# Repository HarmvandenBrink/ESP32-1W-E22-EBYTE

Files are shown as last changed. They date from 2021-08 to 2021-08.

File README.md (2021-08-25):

# ESP32 1W E22-400M30S / E22-900M30S
ESP32-based EBYTE E22-400M30S / E22-900M30S compatible 1 Watt board

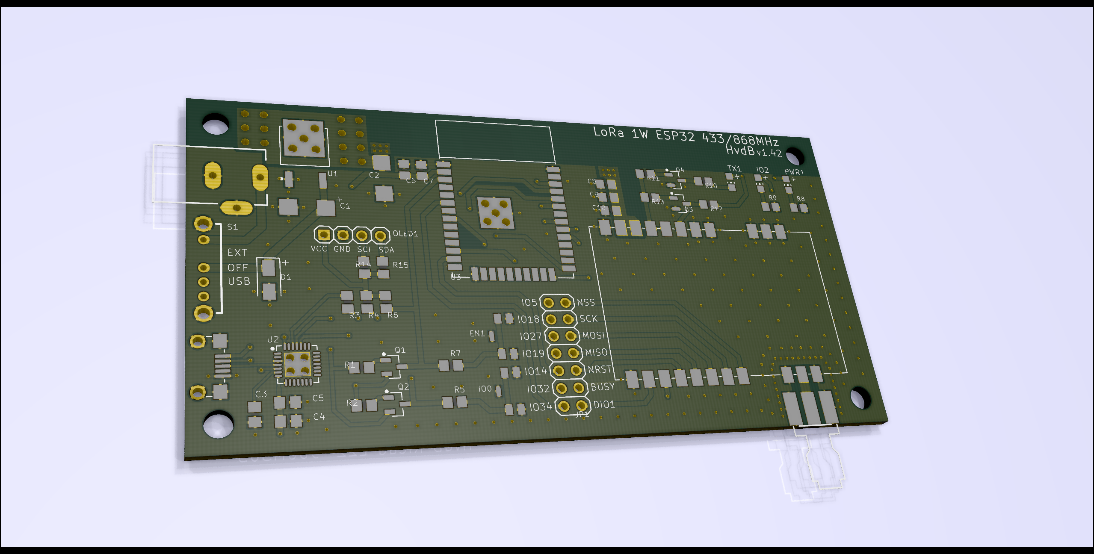
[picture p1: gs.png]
Board design in KiCAD


Forked the design, changed it to KiCAD.

## Features:
* Fully compatible with https://github.com/G4lile0/ESP32-OLED-Fossa-GroundStation
* Radio: Ebyte E22-400M30S / E22-900M30S (http://www.ebyte.com/en/product-view-news.aspx?id=454)
  * SX1268 with TCXO
  * 1W external PA
  * Automatic Rx/Tx switching
  * IPX and SMA connectors
* OLED display
* Selectable power source (USB/external jack)
* Status LEDs: power, Rx/Tx, ESP32 IO2
* On-board USB/UART convertor

Forked from https://github.com/jgromes/ESP32-1W-GroundStation which was Eagle

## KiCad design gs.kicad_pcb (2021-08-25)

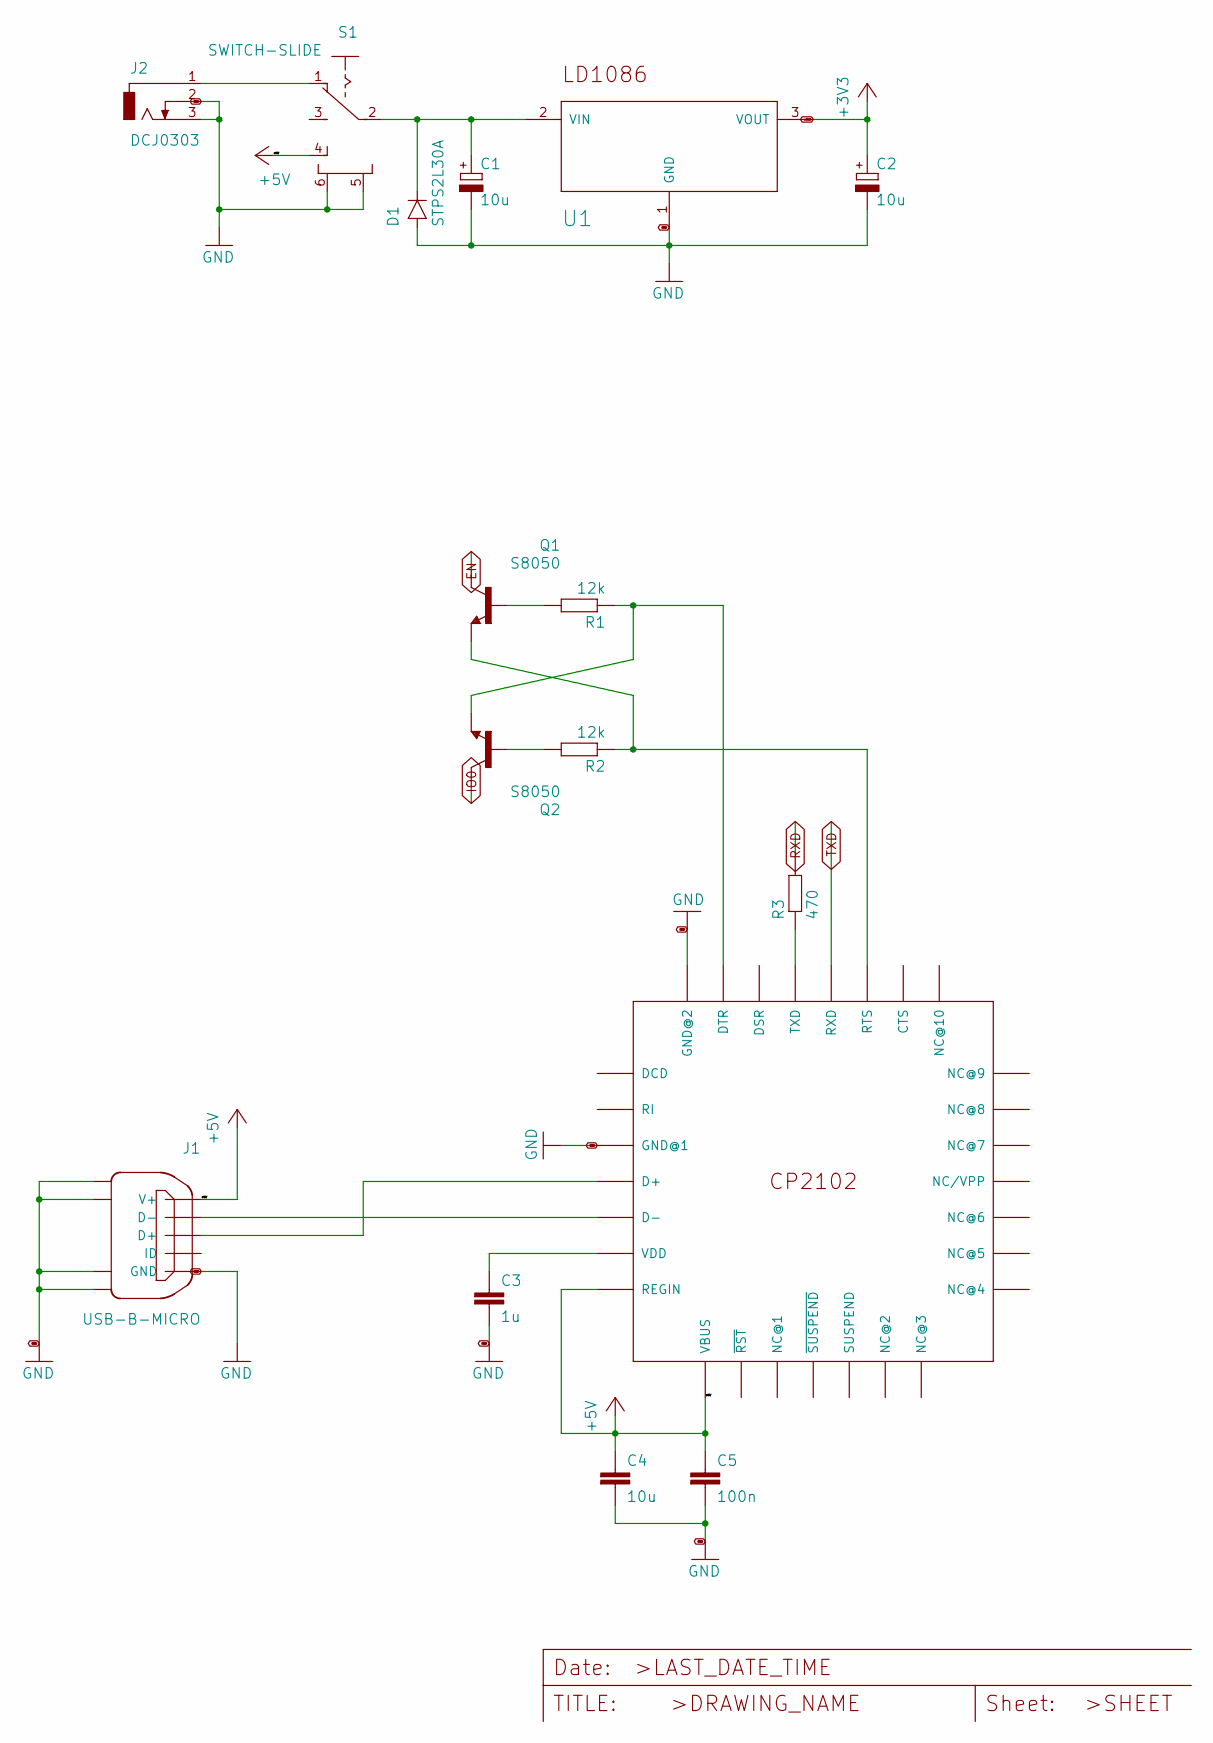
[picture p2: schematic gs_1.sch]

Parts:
C1, C2: 10u; SMC_C
C3: 1u; C0805
C4: 10u; C0805
C5: 100n; C0805
D1: STPS2L30A; DIOM4225X245N
J1: USB-B-MICRO
J2: DCJ0303
Q1, Q2: S8050; SOT95P237X110-3N
R1, R2: 12k; R0805
R3: 470; R0805
S1: SWITCH-SLIDE
U1: LD1086DT33TR; TO228P972X240-3N
U2: CP2102; QFN50P500X500X100-29T300N

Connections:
+3V3: C2.+, U1.3 (VOUT); also elsewhere on the board
+5V: C4.1, C5.1, J1.1 (V+), S1.4, U2.7 (REGIN), U2.8 (VBUS)
EN: Q1.3 (C); also elsewhere on the board
GND: C1.-, C2.-, C3.2, C4.2, C5.2, D1.2 (A), J1.5 (GND), J1.6, J1.7, J1.8, J1.9, J2.2, J2.3, S1.5 (S1), S1.6 (S2), U1.1 (GND), U2.3 (GND@1), U2.29 (GND@2); also elsewhere on the board
IO0: Q2.3 (C); also elsewhere on the board
unnamed: C1.+, D1.1 (C), S1.2, U1.2 (VIN)
unnamed: C3.1, U2.6 (VDD)
unnamed: J1.2 (D-), U2.5 (D-)
unnamed: J1.3 (D+), U2.4 (D+)
unnamed: J2.1, S1.1
unnamed: Q1.1 (B), R1.2
unnamed: Q1.2 (E), R2.1, U2.24 (RTS)
unnamed: Q2.1 (B), R2.2
unnamed: Q2.2 (E), R1.1, U2.28 (DTR)
unnamed: R3.1, U2.26 (TXD)
RXD: R3.2; also elsewhere on the board
TXD: U2.25 (RXD); also elsewhere on the board

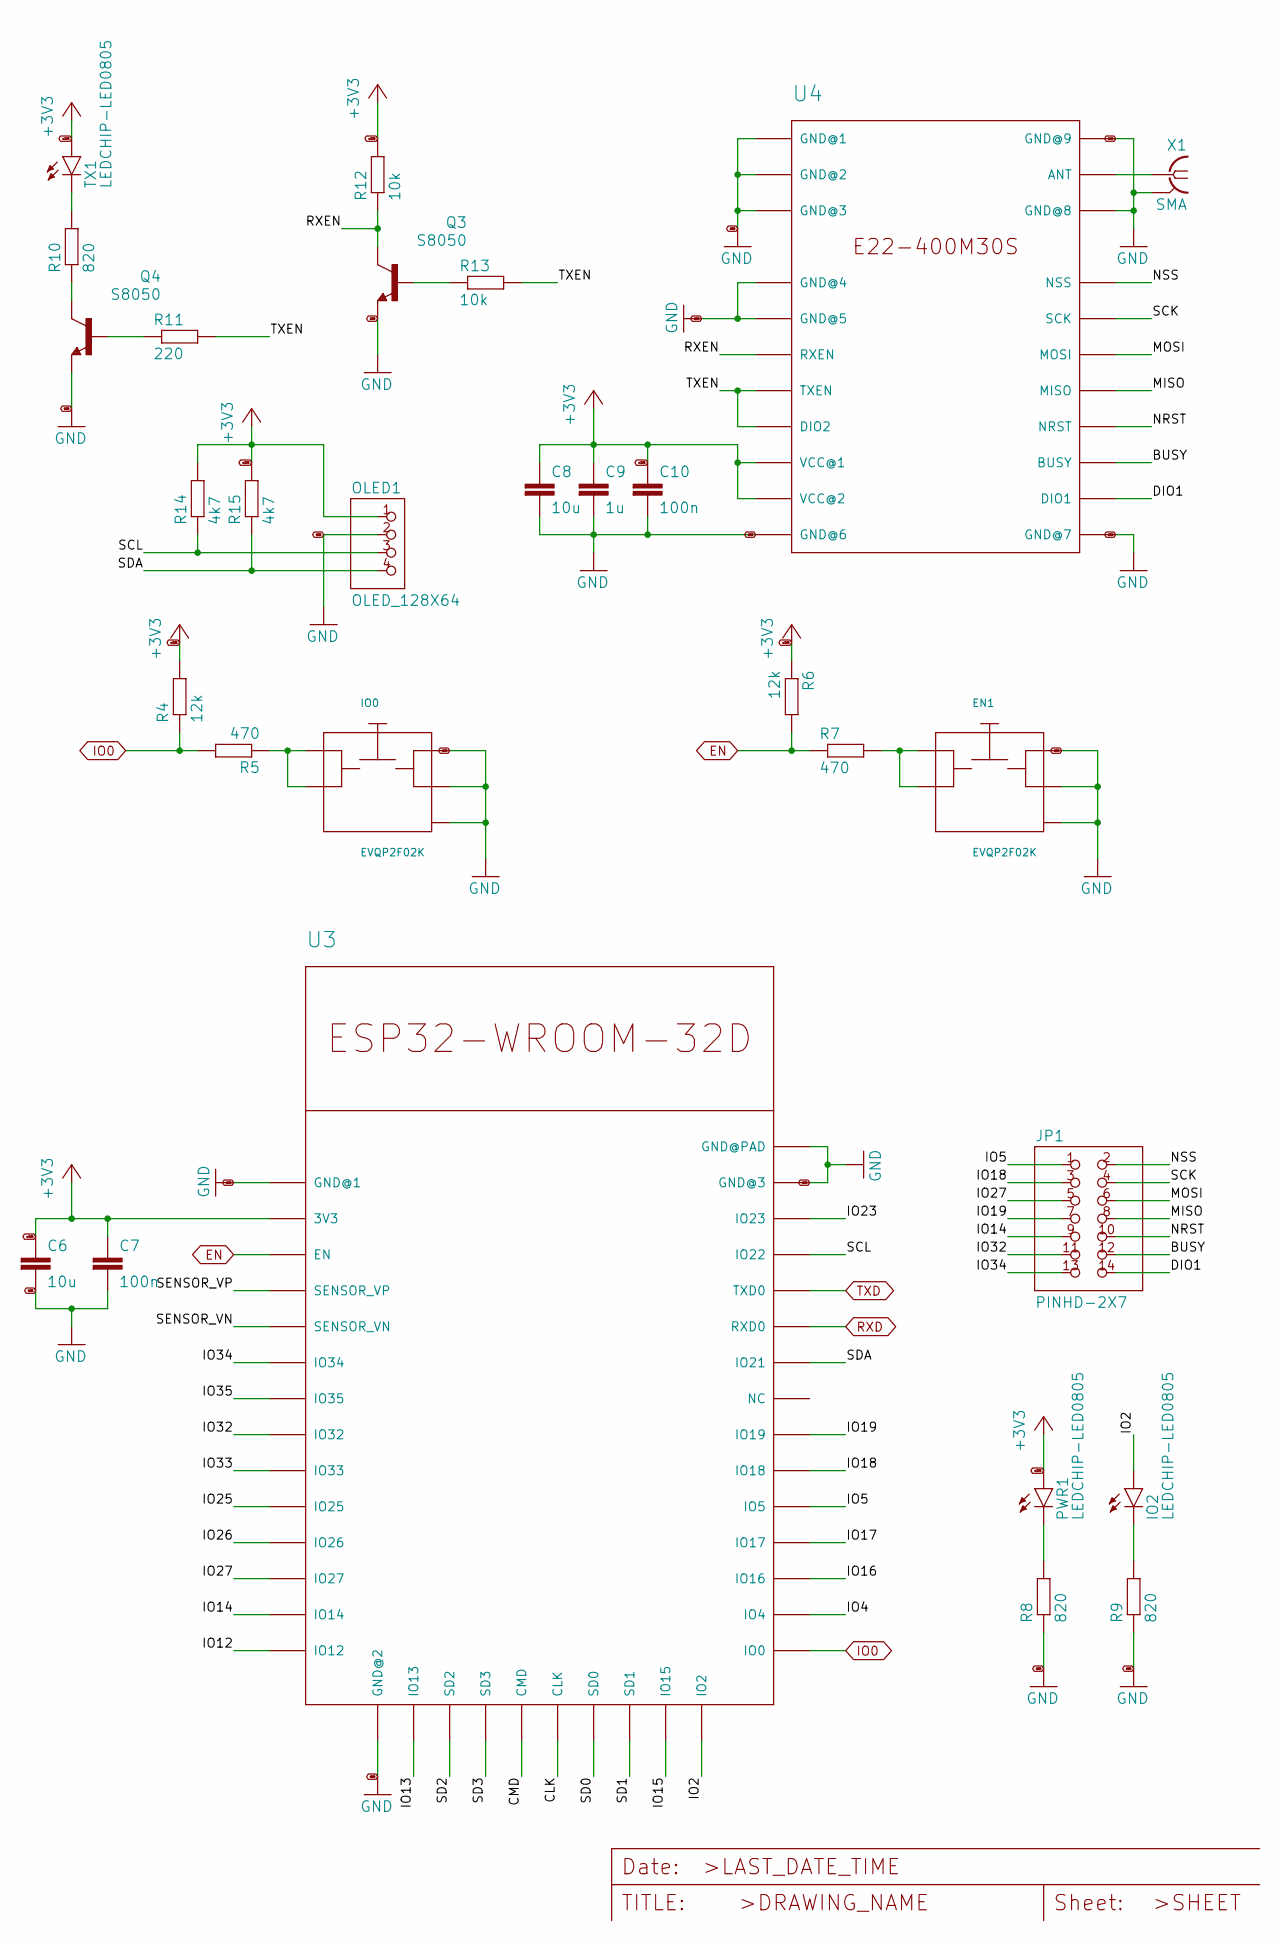
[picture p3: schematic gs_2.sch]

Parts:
C6, C8: 10u; C0805
C7, C10: 100n; C0805
C9: 1u; C0805
EN: EVQP2F02K
IO0: EVQP2F02K
IO2: LEDCHIP-LED0805; CHIP-LED0805
JP1: PINHD-2X7; 2X07
OLED: OLED_128X64
PWR: LEDCHIP-LED0805; CHIP-LED0805
Q3, Q4: S8050; SOT95P237X110-3N
R4, R6: 12k; R0805
R5, R7: 470; R0805
R8, R9, R10: 820; R0805
R11: 220; R0805
R12, R13: 10k; R0805
R14, R15: 4k7; R0805
TX: LEDCHIP-LED0805; CHIP-LED0805
U3: ESP32-WROOM-32D; ESP32-SOLO-1
U4: E22-400M30S
X1: SMA

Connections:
+3V3: C6.1, C7.1, C8.1, C9.1, C10.1, R4.2, R6.1, R12.2, R14.2, R15.2, U3.2 (3V3), U4.9 (VCC@1), U4.10 (VCC@2); also elsewhere on the board
/gs_2/BUSY: JP1.12, U4.14 (BUSY)
/gs_2/CLK: U3.20 (CLK)
/gs_2/CMD: U3.19 (CMD)
/gs_2/DIO1: JP1.14, U4.13 (DIO1)
/gs_2/IO2: IO2.A, U3.24 (IO2)
/gs_2/IO4: U3.26 (IO4)
/gs_2/IO5: JP1.1, U3.29 (IO5)
/gs_2/IO12: U3.14 (IO12)
/gs_2/IO13: U3.16 (IO13)
/gs_2/IO14: JP1.9, U3.13 (IO14)
/gs_2/IO15: U3.23 (IO15)
/gs_2/IO16: U3.27 (IO16)
/gs_2/IO17: U3.28 (IO17)
/gs_2/IO18: JP1.3, U3.30 (IO18)
/gs_2/IO19: JP1.7, U3.31 (IO19)
/gs_2/IO23: U3.37 (IO23)
/gs_2/IO25: U3.10 (IO25)
/gs_2/IO26: U3.11 (IO26)
/gs_2/IO27: JP1.5, U3.12 (IO27)
/gs_2/IO32: JP1.11, U3.8 (IO32)
/gs_2/IO33: U3.9 (IO33)
/gs_2/IO34: JP1.13, U3.6 (IO34)
/gs_2/IO35: U3.7 (IO35)
/gs_2/MISO: JP1.8, U4.16 (MISO)
/gs_2/MOSI: JP1.6, U4.17 (MOSI)
/gs_2/NRST: JP1.10, U4.15 (NRST)
/gs_2/NSS: JP1.2, U4.19 (NSS)
/gs_2/RXEN: Q3.3 (C), R12.1, U4.6 (RXEN)
/gs_2/SCK: JP1.4, U4.18 (SCK)
/gs_2/SCL: R14.1, U3.36 (IO22); also elsewhere on the board
/gs_2/SD0: U3.21 (SD0)
/gs_2/SD1: U3.22 (SD1)
/gs_2/SD2: U3.17 (SD2)
/gs_2/SD3: U3.18 (SD3)
/gs_2/SDA: R15.1, U3.33 (IO21); also elsewhere on the board
/gs_2/SENSOR_VN: U3.5 (SENSOR_VN)
/gs_2/SENSOR_VP: U3.4 (SENSOR_VP)
/gs_2/TXEN: R11.2, R13.2, U4.7 (TXEN), U4.8 (DIO2)
EN: R6.2, R7.1, U3.3 (EN); also elsewhere on the board
GND: C6.2, C7.2, C8.2, C9.2, C10.2, IO0.3, IO0.4, IO0.5, Q3.2 (E), Q4.2 (E), R8.1, R9.1, U3.1 (GND@1), U3.15 (GND@2), U3.38 (GND@3), U3.39 (GND@PAD), U4.1 (GND@1), U4.2 (GND@2), U4.3 (GND@3), U4.4 (GND@4), U4.5 (GND@5), U4.11 (GND@6), U4.12 (GND@7), U4.20 (GND@8), U4.22 (GND@9), X1.G@1 (2), X1.G@2 (2), X1.G@3 (2), X1.G@4 (2); also elsewhere on the board
IO0: R4.1, R5.2, U3.25 (IO0); also elsewhere on the board
unnamed 45: R7.2; also elsewhere on the board
unnamed: IO0.1, IO0.2, R5.1
unnamed: IO2.C, R9.2
unnamed 52: R8.2; also elsewhere on the board
unnamed: Q3.1 (B), R13.1
unnamed: Q4.1 (B), R11.1
unnamed: Q4.3 (C), R10.1
unnamed 61: R10.2; also elsewhere on the board
unnamed: U4.21 (ANT), X1.1
RXD: U3.34 (RXD0); also elsewhere on the board
TXD: U3.35 (TXD0); also elsewhere on the board

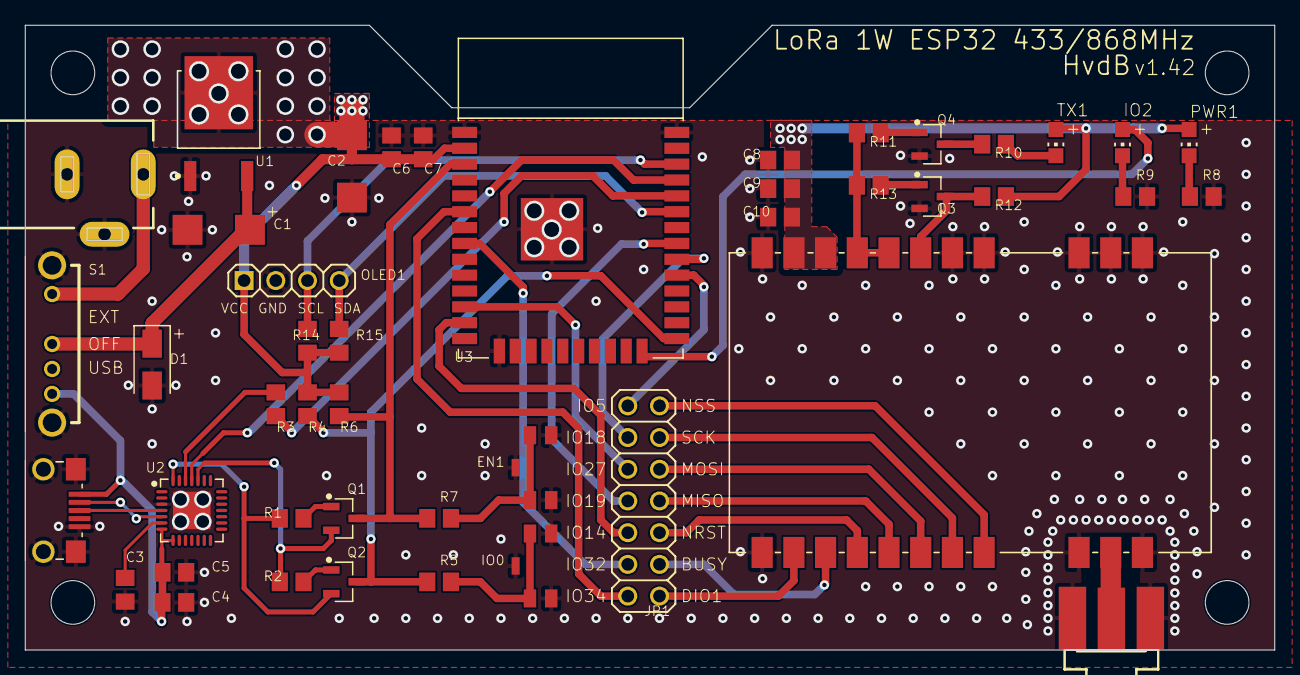
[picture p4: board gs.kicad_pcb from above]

Board: 2 copper layers, 100.1 x 50.0 mm, 49 parts (0 on the bottom side), 45 nets.

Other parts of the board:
@HOLE0, @HOLE1, @HOLE2, @HOLE3: (no value)
EN1: EVQP2F02K
OLED1: OLED_128X64
PWR1: LEDCHIP-LED0805; CHIP-LED0805
TX1: LEDCHIP-LED0805; CHIP-LED0805

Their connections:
+3V3: OLED1.1, PWR1.A, TX1.A; also elsewhere on the board
/gs_2/SCL: OLED1.3; also elsewhere on the board
/gs_2/SDA: OLED1.4; also elsewhere on the board
GND: EN1.3, EN1.4, EN1.5, OLED1.2; also elsewhere on the board
unnamed 45: EN1.1, EN1.2; also elsewhere on the board
unnamed 52: PWR1.C; also elsewhere on the board
unnamed 61: TX1.C; also elsewhere on the board
